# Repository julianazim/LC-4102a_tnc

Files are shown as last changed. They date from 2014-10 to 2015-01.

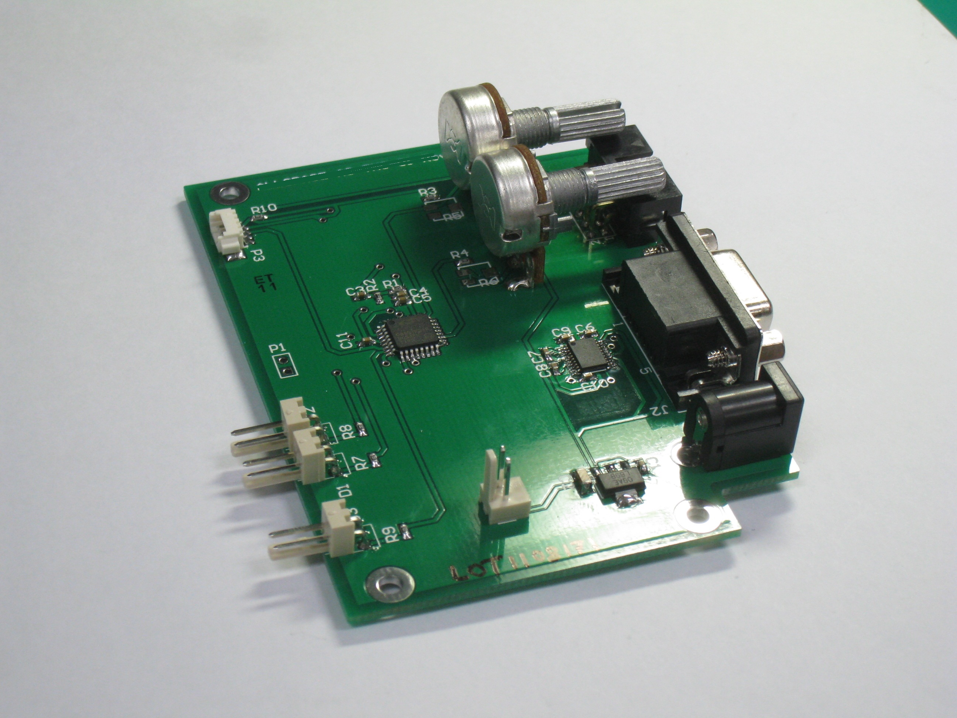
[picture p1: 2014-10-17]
documentation/pictures/IMG_1895.JPG

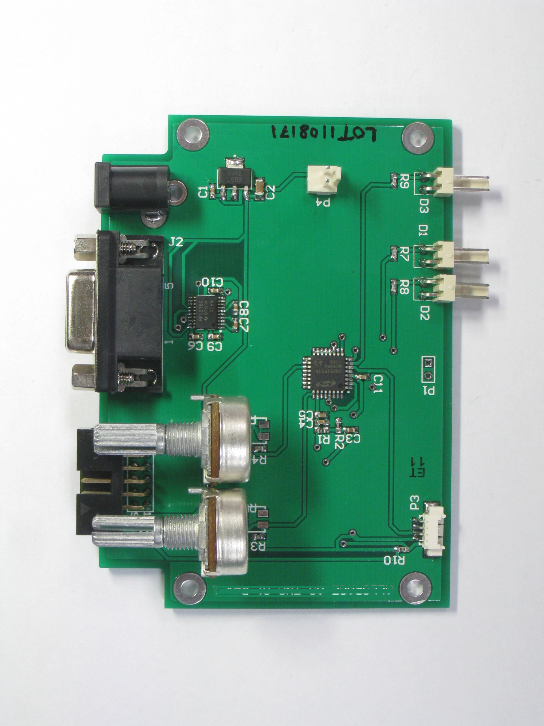
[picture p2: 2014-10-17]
documentation/pictures/IMG_1900.JPG

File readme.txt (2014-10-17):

--------------------------
LibreCube LC-4102a 1k2 TNC
--------------------------

OVERVIEW
--------
The LC-4102a 1k2 TNC Terminal Node Controller is used at the ground station
for interfacing between a computer system (running a mission control system)
and a radio system, for the  upload of telecommands and the reception of 
telemetry via the space link. The device is designed for the use of ECSS/CCSDS
conform telecommand and telemetry frames. It utilizes a simple protocol for
interfacing to a standard PC via serial port.

DISCLAIMER
----------
This product package is distributed in the hope that it will be useful, but 
WITHOUT ANY WARRANTY; without even the implied warranty of MERCHANTABILITY or 
FITNESS FOR A PARTICULAR PURPOSE. See the applicable licenses for more details.

AUTHORS
-------
Release a
* Artur Scholz <artur.scholz@cubesat.de>

ACKNOWLEDGEMENTS
----------------
The original work (Release a) was carried out at and with support from 
National Cheng Kung University (www.ncku.edu.tw) under supervision of 
Prof. Jiun-Jih Miau and Prof. Jyh-Ching Juang and with the help from students 
of PACELAB and MECLAB of National Cheng Kung University.

RELEASE HISTORY
---------------
Release a
* First release

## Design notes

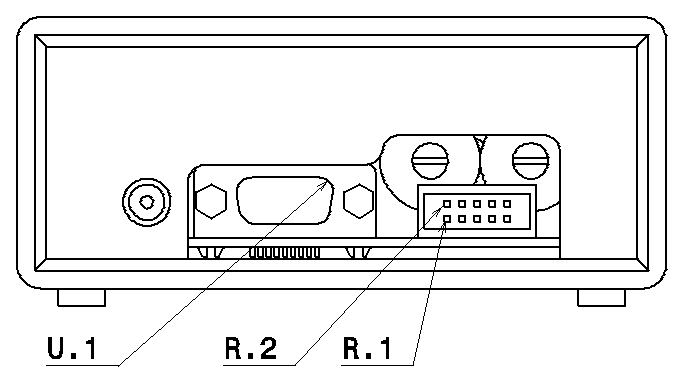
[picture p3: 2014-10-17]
documentation/figures/connector layout.tif

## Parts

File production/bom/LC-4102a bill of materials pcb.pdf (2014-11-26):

Sheet1

Page 1

LC-4102a Bill of Materials, PCB

Pos | Type | Description | Reference Designators | Qty | Vendor | Part Number | Unit Cost | Total Cost
1 | C | 0.1 uF | C1, C6, C7, C8, C9, C10, C11 | 7 | Digikey | 490-5241-1-ND | 0.10 € | 0.70 €
2 | C | 2.2 uF | C3 | 1 | Digikey | 587-1263-1-ND | 0.13 € | 0.13 €
3 | C | 10 uF | C2 | 1 | Digikey | 587-2562-1-ND | 0.56 € | 0.56 €
4 | C | 470 pF | C4, C5 | 2 | Digikey | 1276-2302-1-ND | 0.09 € | 0.18 €
5 | IC | C8051F310 | U3 | 1 | Digikey | 336-1252-ND | 3.86 € | 3.86 €
6 | IC | LM2937-3.3 | U1 | 1 | Digikey | LM2937IMP-3.3CT-ND | 1.93 € | 1.93 €
7 | IC | MAX3223 | U2 | 1 | Digikey | 296-13092-1-ND | 2.22 € | 2.22 €
8 | LED | LED1 | D1, D2, D3 | 3 | Digikey | 160-1447-1-ND | 0.26 € | 0.78 €
9 | P | DSUB9 | J2 | 1 | Digikey | 609-4009-ND | 0.83 € | 0.83 €
10 | P | Header 2 | P1, P4 | 2 | Digikey | 732-2699-ND | 0.51 € | 1.02 €
11 | P | Header 5X2-R | P2 | 1 | Digikey | 3M15452-ND | 0.65 € | 0.65 €
12 | P | MICRO-04-R-SMT | P3 | 1 | Digikey | WM7622CT-ND | 1.08 € | 1.08 €
13 | P | MINIJACK-1.3 | J1 | 1 | Digikey | CP-2519-ND | 0.76 € | 0.76 €
14 | R | 1 k | R3, R4, R7, R8, R9, R10 | 6 | Digikey | P1.0KGCT-ND | 0.09 € | 0.54 €
15 | R | 100 k | R2 | 1 | Digikey | P100KGCT-ND | 0.09 € | 0.09 €
16 | R | 120 k | R1 | 1 | Digikey | P120KGCT-ND | 0.09 € | 0.09 €
17 | R | 1 k | R5, R6 | 2 | Digikey | 987-1313-ND | 0.73 € | 1.46 €
Total: | 16.88 €

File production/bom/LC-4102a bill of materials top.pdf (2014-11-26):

Sheet1

LC-4102a Bill of Materials, Top Level

Item | Description | Reference Designators | Qty | Part Number (Digi-Key)
1 | PCB | | 1 | *produce
2 | Casing | | 1
3 | Power switch | | 1
4 | LED | | 3

Sheet1

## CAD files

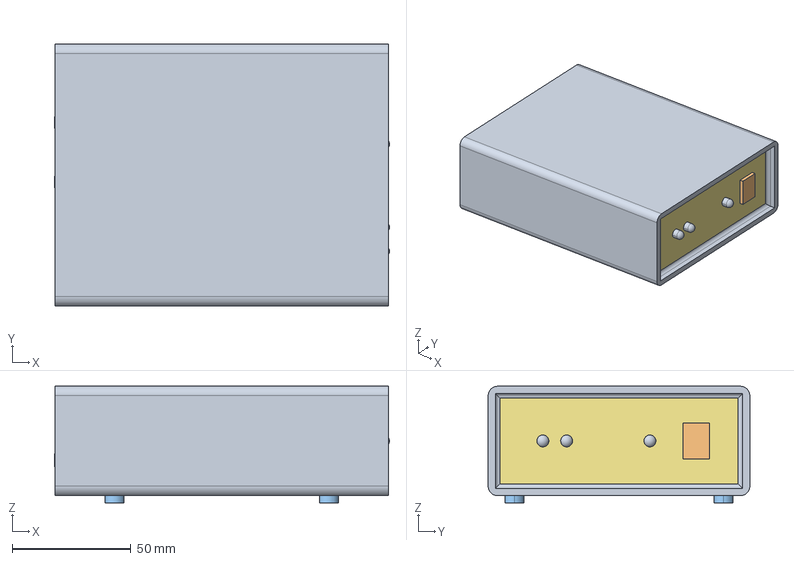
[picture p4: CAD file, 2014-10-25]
design/mechanical/assembly.stp
140.8 x 110.0 x 49.0 mm

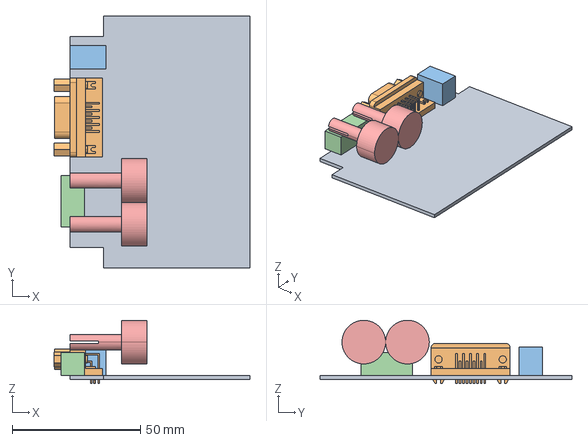
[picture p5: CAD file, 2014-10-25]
design/mechanical/board/pcb tnc assembly.stp
76.3 x 98.0 x 24.7 mm

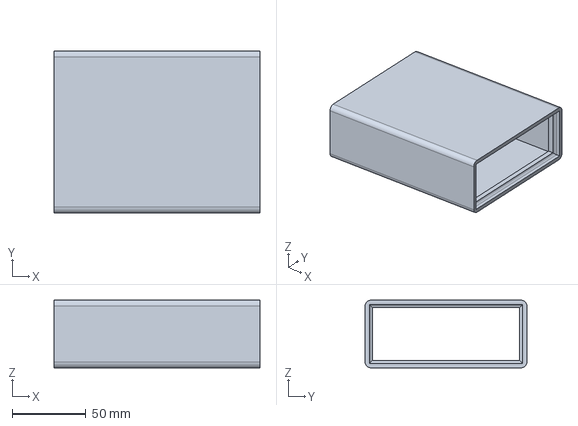
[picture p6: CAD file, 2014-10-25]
design/mechanical/parts/case.stp
140.0 x 110.0 x 46.0 mm

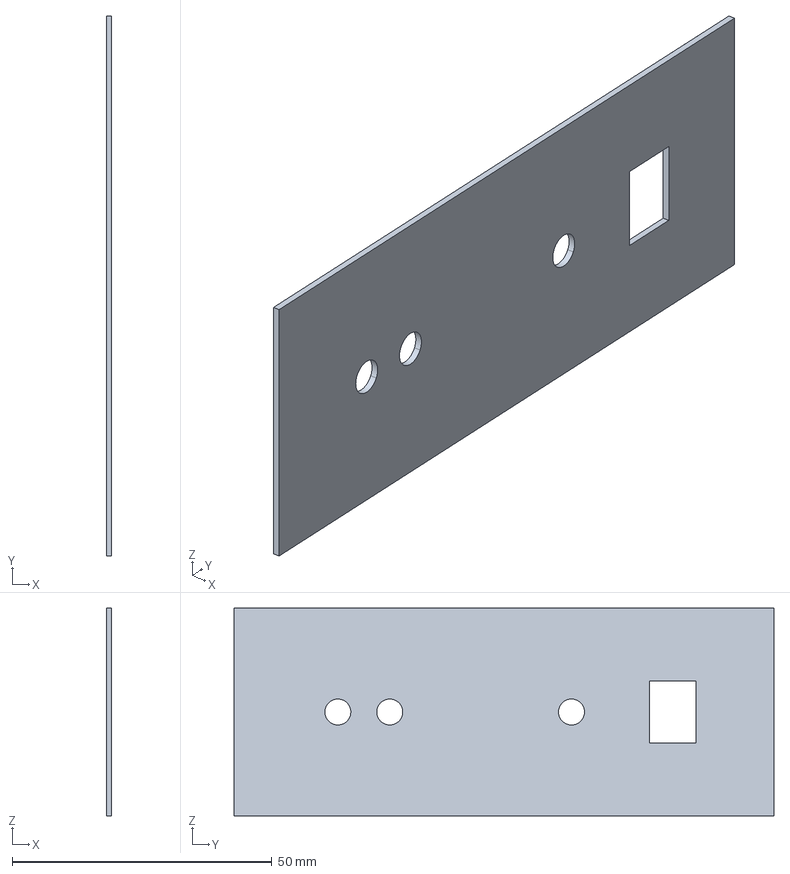
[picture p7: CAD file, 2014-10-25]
design/mechanical/parts/front panel.stp
1.00 x 104.0 x 40.0 mm

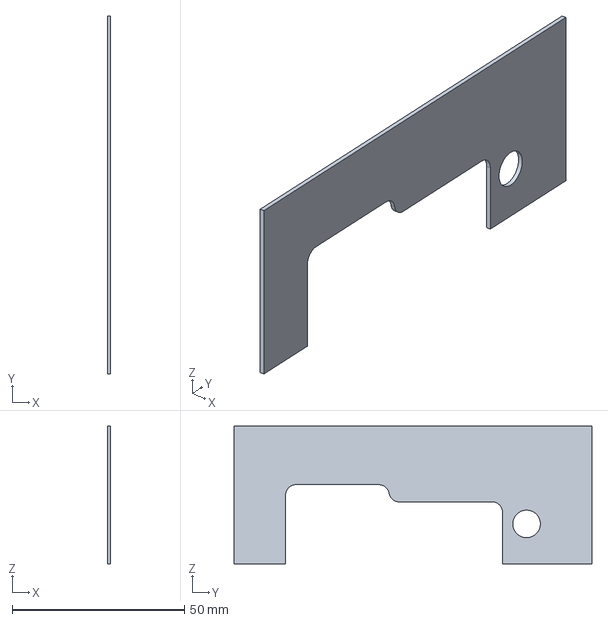
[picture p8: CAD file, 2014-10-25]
design/mechanical/parts/back panel.stp
1.00 x 104.0 x 40.0 mm

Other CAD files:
design/mechanical/assembly.CATProduct
design/mechanical/assembly.igs
design/mechanical/board/parts/connector.CATPart
design/mechanical/board/parts/dsub9.CATPart
design/mechanical/board/parts/pcb tnc.CATPart
design/mechanical/board/parts/plug.CATPart
design/mechanical/board/parts/poti.CATPart
design/mechanical/board/pcb tnc assembly.CATProduct
design/mechanical/board/pcb tnc assembly.igs
design/mechanical/parts/back panel.CATPart
design/mechanical/parts/back panel.igs
design/mechanical/parts/back panel.stl
design/mechanical/parts/case.CATPart
design/mechanical/parts/case.igs
design/mechanical/parts/case.stl
design/mechanical/parts/front panel.CATPart
design/mechanical/parts/front panel.igs
design/mechanical/parts/front panel.stl
design/mechanical/parts/led.CATPart
design/mechanical/parts/standoff.CATPart
design/mechanical/parts/switch.CATPart

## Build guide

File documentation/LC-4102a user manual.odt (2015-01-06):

LC-4102a

Terminal Node Controller

Document change log

Rev. | Date | Author | Pages | Description
0 | 2014-10-17 | Artur Scholz | All | Initial release

# Introduction

The LC-4102a Terminal Node Controller is used at the ground station for interfacing between a computer system (running a mission control system) and a radio system. The device is designed for the use of ECSS/CCSDS telecommand and telemetry frames. It utilizes a simple protocol for interfacing to a standard PC via serial port.

Features:

- ECSS/CCSDS frame protocol for telecommands
- Modified KISS protocol for TNC to PC communication
- Fixed FSK mode operation at 1200 bps

# Applicable and reference documents

Reference | Title | Issue
RD01 | KISS protocol, http://www.ax25.net/kiss.aspx | -
RD02 | ECSS-E-ST-50-01C, Space data links – Telemetry synchronization and channel coding | -
RD03 | ECSS-E-ST-50-04C, Space data links – Telecommand protocols synchronization and channel coding | -

# Definitions and abbreviations

Abbreviation | Definition
ASM | Attached sync marker
CADU | Channel Access Data Unit
CCSDS | Consultative Committee for Space Data Systems
CLTU | Communications Link Transmission Unit
ECSS | European Cooperation on Space Standardization
FEND | Frame end
FESC | Frame escape
KISS | Keep it simple, stupid
MSB | Most significant bit
PTT | Push to talk
RF | Radio frequency
RSSI | Received signal strength indication
TC | Telecommand
TFESC | Transposed frames escape
TM | Telemetry

# Specification

## Absolute maximum ratings

Parameter | Min | Max | Unit
Supply voltage | | 26 | V

## Physical characteristics

Parameter | Min | Nom | Max | Unit
Mass | | 225 | | g
Height | | 46 | | mm
Width | | 110 | | mm
Depth | | 140 | | mm

## Electrical characteristics

Parameter | Min | Nom | Max | Unit
Supply voltage | | 9 | | V
Power consumption | | | 4.5 | W
Microcontroller operating frequency | | 24.5 | | MHz
UART baud rate | | 115200 | | bps
DATAOUT output level | 0 | | 1.65 | V
DATAIN bias level | 0 | | 1.65 | V

## RF and protocol characteristics

Parameter | Min | Nom | Max | Unit
FSK baud rate | | 1200 | | bps
Size of CLTU | | | 140 | Byte
Fixed size of CADU | 16 | 64 | 2048 | Byte

# Interfaces

## Mechanical interfaces

The mechanical layout of the device and its dimensions are shown in Illustration 1. A short description of all items is provided in Table 1.

Illustration 1: Mechanical layout

Table 1: Description of front and back panel elements

Element | Function
RX LED | Indicates that frames are being received
TX LED | Indicates that transmission is active
POWER LED | Indicates that device is powered
POWER SWITCH | For switching the device on and off
POWER JACK | 9 Volt power supply input, ø2.1 mm, center positive
SERIALPORT CONNECTOR | Serial port for connection to PC
RADIO CONNECTOR | Connects to the radio
TX LEVEL ADJUSTMENT | Adjust output level for DATAOUT (TX)
RX BIAS ADJUSTMENT | Adjust bias level for DATAIN (RX)

## Electrical interfaces

The electrical interfaces to the device are shown in Illustration 2 and described in Table 2, Table 3, and Table 4.


Illustration 2: Connector layout

Table 2: Radio connector

Pin | Signal | Description
R.1 | - | Do not connect
R.2 | +3.3V | +3.3 Volt output
R.3 | ADJ0 | For adjustment
R.4 | DATAIN | Input for data (from external radio)
R.5 | ADJ1 | For adjustment
R.6 | -PTT | Push-to-talk input. Active low
R.7 | ADJ2 | For adjustment
R.8 | DATAOUT | Output of data (to external radio)
R.9 | GND | Ground
R.10 | GND | Ground

* Only the bold printed connections need to be wired to the radio

Table 3: Serial port connector

Pin | Signal | Description
U.2 | RXD_TTL | RXD (TTL level)
U.3 | TXD_TTL | TXD (TTL level)
U.5 | GND | Ground

Table 4: Programming interface connector

Pin | Signal | Description
PI.1 | +3.3V | +3.3V power supply
PI.2 | C2D | C2 programming interface data
PI.3 | C2CK | C2 programming interface clock
PI.4 | GND | Ground.

* This connector is located on the PCB.

| The programming interface is used for updating the firmware.

## Software interfaces

Interfacing between the TNC and a computer for transfer of beacon/telemetry and telecommand data is accomplished via the UART bus.

The protocol is kept very simple, in close analogy to the KISS protocol (RD01). Data is transferred in frames between master and slave, one frame after the other. Frames are delimited by a special FEND (Frame End) character at the start and end. The first byte of a frame following the delimiter indicates the type of data in the frame.

FEND | CMD | Data | Data | Data | Data | ... | Data | FEND

The values of the special characters are:

FEND Frame End 0xC0

FESC Frame Escape 0xDB

TFEND Transposed Frame End 0xDC

TFESC Transposed Frame Escape 0xDD

In case that a FEND character appears in the data, it is translated into the two byte sequence FESC TFEND (Frame Escape, Transposed Frame End). Likewise, if the FESC character ever appears in the user data, it is replaced with the two character sequence FESC TFESC (Frame Escape, Transposed Frame Escape).

As characters arrive at the receiver side, they are appended to a buffer containing the current frame. Receiving a FEND marks the end of the current frame. Receipt of a FESC puts the receiver into "escaped mode", causing the receiver to translate a following TFESC or TFEND back to FESC or FEND, respectively, before adding it to the receive buffer and leaving escaped mode. Receipt of any character other than TFESC or TFEND while in escaped mode is an error; no action is taken and frame assembly continues. A TFEND or TESC received while not in escaped mode is treated as an ordinary data character.

The CMD byte can have take following values:

UPLINK_CLTU 0x01 CLTU to be sent from computer to TNC

DOWNLINK_CADU 0x02 CADU received from TNC to computer

HANDSHAKE 0x0A Handshake (answer)

TEST_CONNECTION 0x0B Test port connection

TX_STATE 0x0C Transmitter state (on/off)

IDLE_SEQUENCE 0x0D Send idle pattern (on/off)

CADU_LENGTH 0x0E Set the fixed CADU length

See Section Operations on how to use those commands.

# Design description

## Hardware description

The TNC consists of a power conditioner, a UART interface module, and microcontroller. The microcontroller handles the interfacer to the computer via the UART interface module. It further provides the interface to an external radio, and conditions its input and output.

For the output of data to the external radio (i.e. DATAOUT line), it provides the capability to adjust the signal level for a binary '1' from 0V to 1.65V (binary '0' is always at ground).

For the input of data from the external radio (i.e. DATAIN line) it first removes the DC offset from the signal through a high pass filter. It then compares the incoming signal level with an adjustable reference signal level, to discriminate between binary '1'and '0'.

## Software description

The TNC provides is the node between computer and radio system for sending telecommand frames (CLTUs) and receiving telemetry frames (CADUs).

When not sending, the TNC continuously reads from the radio output, shifts these bits into a small buffer, and checks if the synch pattern (ASM) has been detected. It then receives the CADU (i.e. telemetry) frame bit for bit, shifts it into an octet buffer (i.e. byte buffer) and sends appends each completed octet to the frame being send to the computer via the KISS protocol. Since CADU frames have fixed length, the TNC knows when a full CADU has been received and then terminates the transfer to the computer.

For sending of CLTUs (i.e. telecommands) the computer first switches on the transmitter, then activates the sending of acquisition sequence (which is composed of idle pattern) and then transfers the CLTU via the KISS protocol to the TNC. Once the whole CLTU has been transferred, the TNC starts to transmit the CLTU bit stream to the radio, provided that the transmitter is left enabled. The computer finishes the transmit session by switching of the transmitter.

# Installation

## Making the connections

Plug a serial cable to the device and connect it with a PC (for example by using a serial to USB cable). Make sure that the device power switch is off and then plug a 9V power supply to the device. Finally, connect the bold written pins in Table 2 from the device’s radio connector to the radio’s data connector. For proper operation, the device must be adjusted to the radio’s signal levels. This is described in the next sections.

## Transmit adjustments

Refer to your radio for the specification on the recommended and allowable input levels on its DATA IN pin. Commonly this is about 0.4 Vpeak-peak.

To adjust the output level of the DATAOUT signal, temporarily disconnect the DATAOUT signal line from the device’s radio connector and measure its voltage level. Rotate the TX LEVEL ADJUSTMENT potentiometer clockwise to increase and counter-clockwise to decrease the output level to the desired value.

| Note: Same commercial radios output an inverted bit stream. In such case, one needs to set the bit invert flag in the TNC.

## Receive adjustments

The device requires that the radio recovers the FSK modulated baseband signal from the RF signal fairly accurately. Internally, the device decouples and filters the signal provided by the radio and makes this signal available at the ADJ1 pin. An example of this signal when the radio receives only noise is shown in Illustration 3. Make sure that your radio is tuned properly to produce similar results. Determine the mean value of this signal, as shown as the red line.

Illustration 3: Raw signal from radio (top) and filtered signal at ADJ1 (bottom)

Next, adjust the signal at the ADJ2 pin to this previously determined mean value, by using the RX BIAS ADJUSTMENT potentiometer clockwise for decrease or counter-clockwise for increase. The meaning of this bias voltage is that every signal level of the filtered signal in Illustration 4 that is above this threshold will be converted to 3.3 V whereas all signals below this threshold will be converted to 0V (CMOS level) for use by the TNC. As a last step, measure the signal at ADJ0 to see the recovered binary sequence in CMOS level.

Illustration 4: The filtered radio signal (top) correctly converted into CMOS level (bottom).

# Operations

## Testing the connection

To ensure that the device is connected correctly to the computer and the KISS frames exchange works properly, the TEST_CONNECTION command can be used.

The computer sends an TEST_CONNECTION frame via the serial port, with following structure:

FEND | CMD | FEND

Where CMD = TEST_CONNECTION. The TNC then responds with an acknowledge frame:

FEND | CMD | FEND

Where CMD = HANDSHAKE.

## Adjusting TNC settings

So far, the only setting that can be adjusted via software is the length of the CADU frame. CADU frames have (mission) fixed length. This is so because they only have markers for the start of a frame (i.e. the attached synch marker) and not for the frame end. Therefore they must be fixed length, to let the TNC know when the frame is complete.

## Receiving

When not transmitting, the TNC is constantly in receive mode. It searches the incoming bit stream from the radio for the synch pattern (ASM), which marks the begin of a CADU, which is used to transport telemetry from the spacecraft. The structure of a CADU is as follows:

CADU – Channel Access Data Unit
Attached Synch Marker 0x1ACFFC1D | Data
4 byte | Fixed, max. 2048 byte

When the TNC has detected an ASM, it will start a KISS frame transfer (sending a FEND) and then transfer the received CADU while it is being received, as follows:

FEND | CMD | CADU | FEND

Where CMD = DOWNLINK_CADU. Note again that the CADU frame is transferred at the same time while it is being received, meaning that there is no buffering of the whole CADU at the TNC. This is possible because the UART connection always to introduce delays in the transfer.

## Transmitting

For transmitting CLTUs (i.e. telecommands), the computer shall operate the TNC in the following manner.

First, the transmitter must be turned on. This is accomplished via the following KISS frame:

FEND | CMD | PAR | FEND

Where CMD = TX_STATE, and PAR = ON. This mode is equivalent to CMM-1 “Unmodulated carrier only”, as defined in RD03.

Then the sending of the acquisition sequence shall be activated, which is an idle pattern, i.e. a sequence of alternating “ones” and “zeros” starting with either a “one” or a “zero”. This is a preamble that provides for initial symbol synchronization for the received on board the satellite. It should be sending at least 128 bits before switching to CMM-3. The command is as follows:

FEND | CMD | PAR | FEND

Where CMD = IDLE_SEQUENCE, and PAR = ON. This mode is equivalent to CMM-2 “Carrier modulated with acquisition sequence”, as defined in RD03.

Then the sending of a CLTU can be initiated as follows:

FEND | CMD | CLTU | FEND

Where CMD = UPLINK_CLTU and the CLTU is structured as follows:

CLTU – Command Link Transmission Unit
Start Sequence 0xEB90 | 1st Codeblock | 2nd Codeblock | ... | n-th Codeblock | Tail sequence
2 byte | 8 byte | 8 byte | | 8 byte | 8 byte

A CLTU is of variable length and terminated by a tail sequence, which can be either:

“0xC5 0xC5 0xC5 0xC5 0xC5 0xC5 0xC5 0x79” or “0x55 0x55 0x55 0x55 0x55 0x55 0x55 0x55”

The sending of a CLTU is described as mode CMM-3 “Carrier modulated with telecommand data”, as defined in RD03. Several CLTUs can be send during one transmit session (i.e. while the transmitter is on), provided that there is a small amount of idle bits being sent in between (which is then defined as mode CMM-4 “Carrier modulated with idle sequence”). The length of the idle sequence shall be at least 8 bits. This is achieved easily by waiting for short delay between the sending of CLTUs, while sending of acquisition sequence is left enabled. The transmit session is ended by stopping the transmission of the acquisition sequence and switching of the transmitter (see IDLE_SEQUENCE and TX_STATE commands above, both with parameter OFF).

Terminal Node Controller Ref : LC-4102a-MAN-001 Issue : 1 Rev. : 0 Date : 2014-10-17 Page : 14

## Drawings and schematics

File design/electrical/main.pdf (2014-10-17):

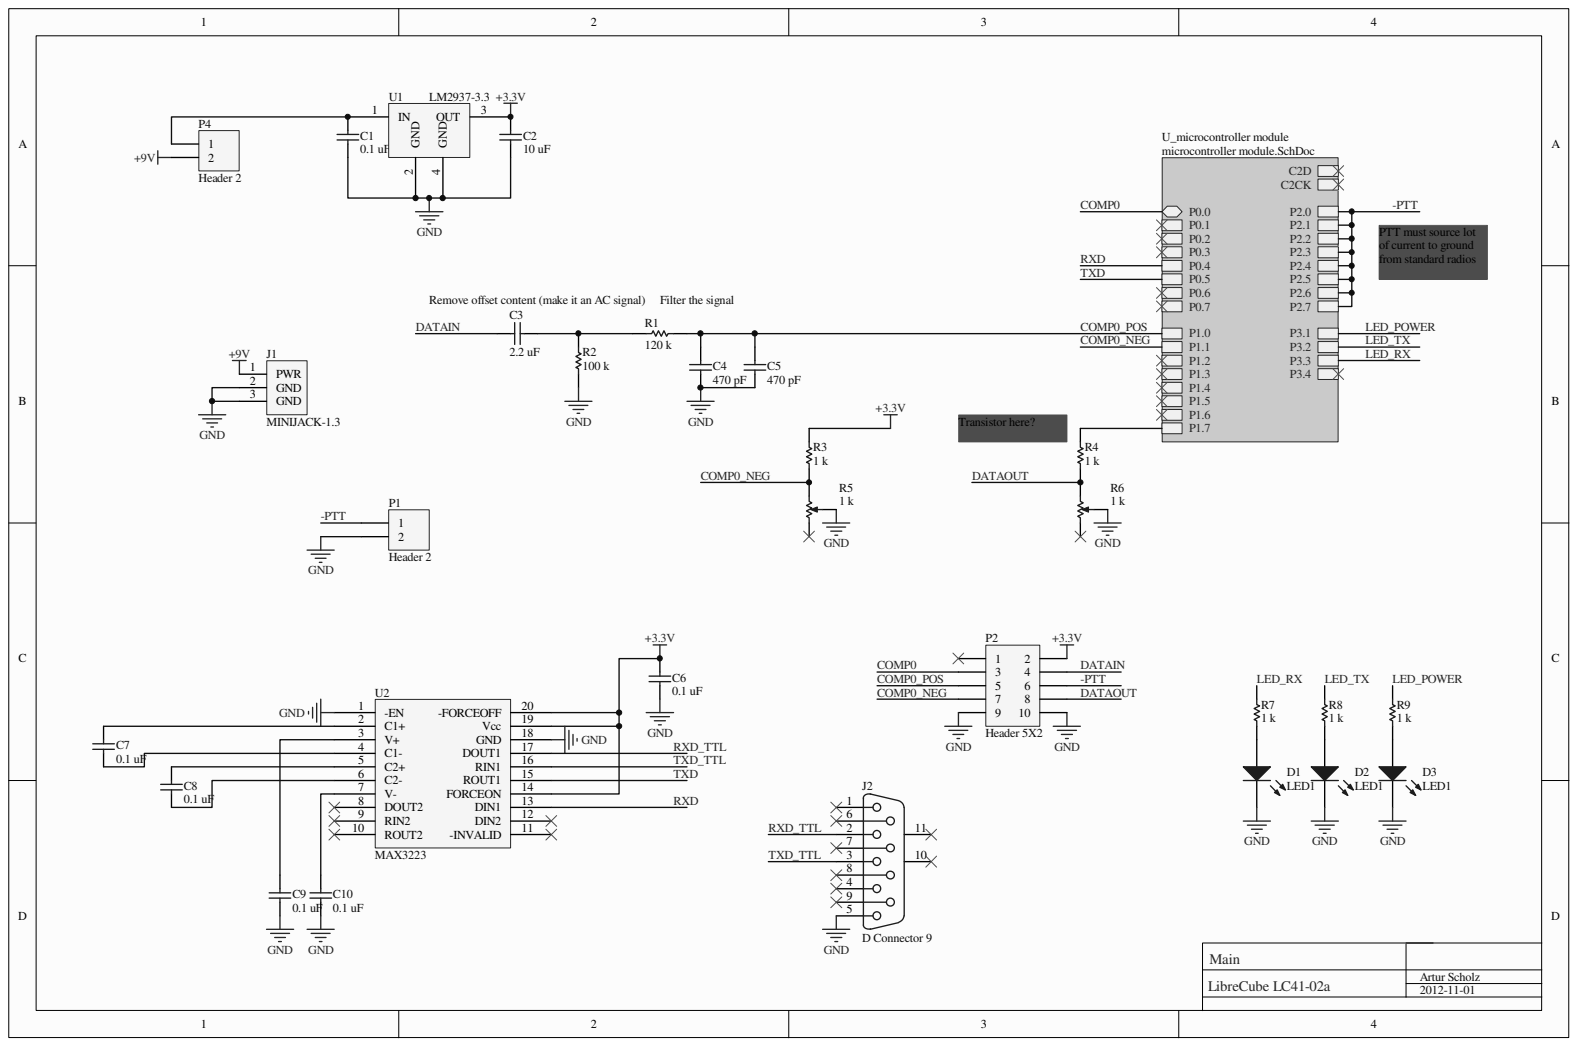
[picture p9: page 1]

PTT must source lot
of current to ground
from standard radios

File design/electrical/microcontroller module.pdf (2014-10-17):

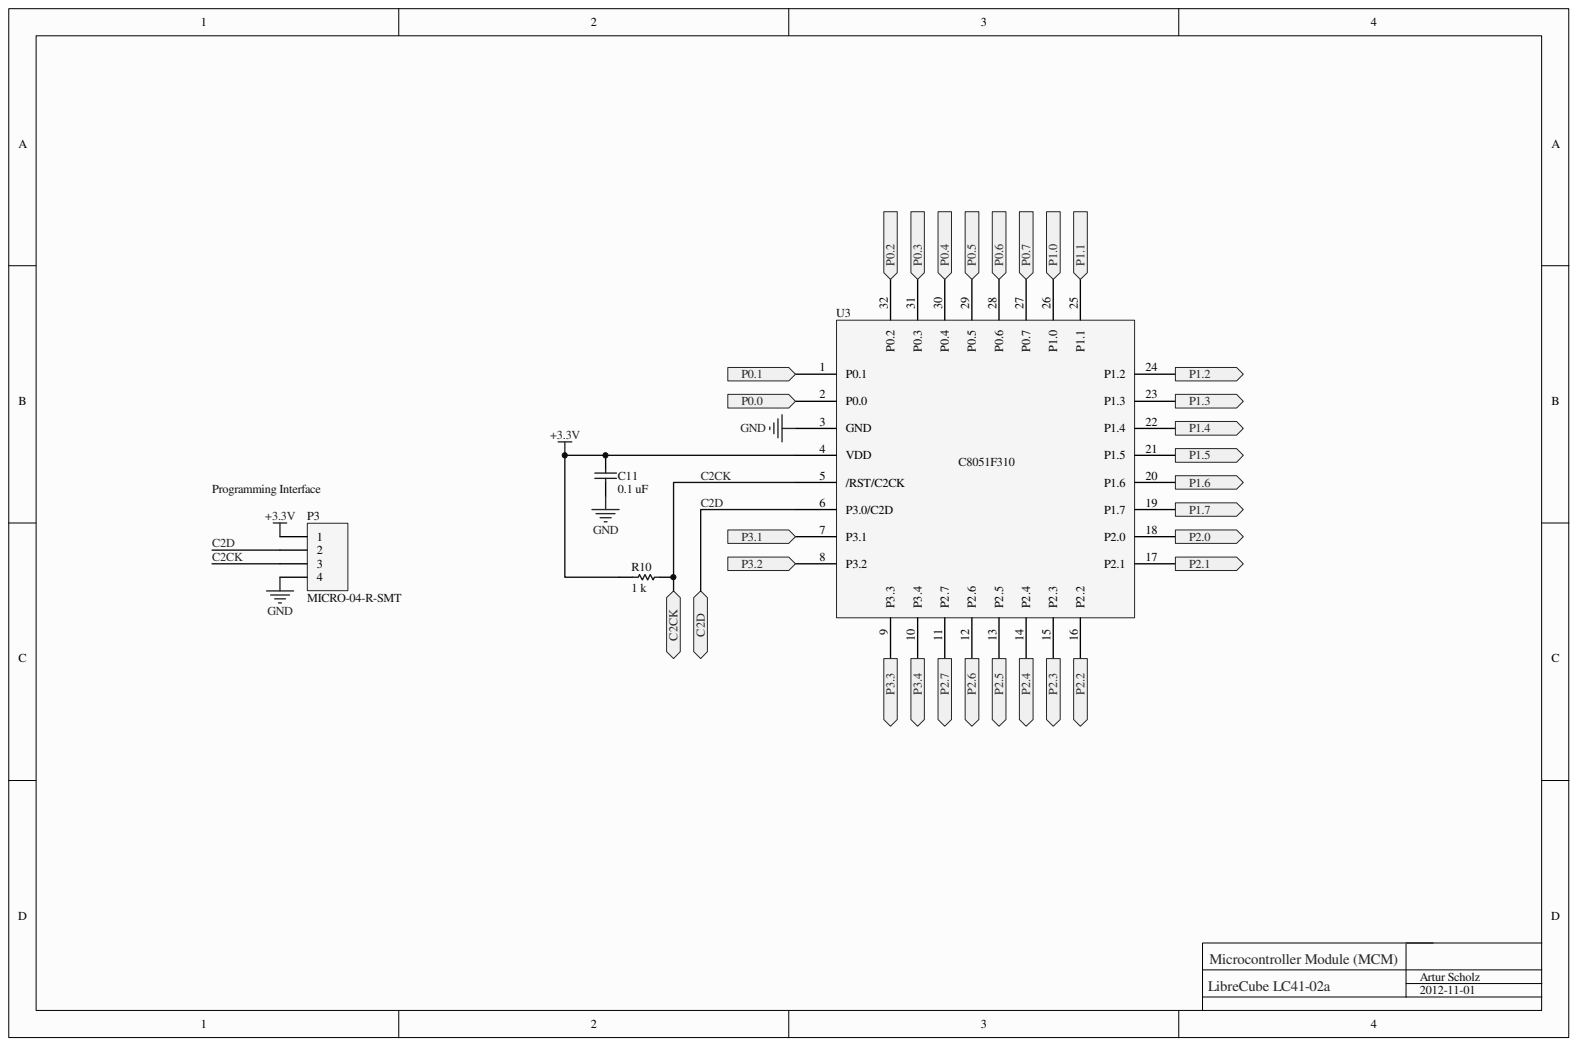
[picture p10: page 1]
Artur Scholz; LibreCube LC41-02a; MICRO-04-R-SMT; GND; Programming Interface; GND 3; VDD 4; /RST/C2CK 5

Microcontroller Module (MCM)

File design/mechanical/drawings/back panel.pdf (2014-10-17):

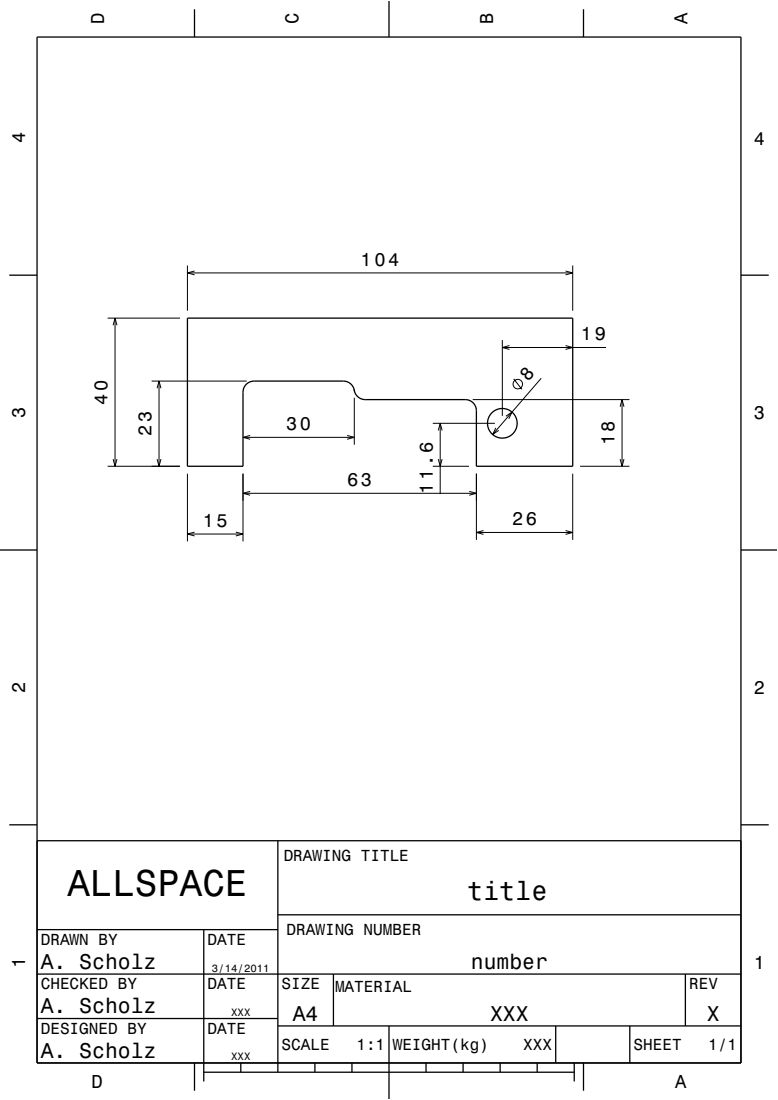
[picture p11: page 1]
DRAWING NUMBER; DRAWING TITLE

DRAWN BY A. Scholz | DATE 3/14/2011

CHECKED BY A. Scholz | DATE XXX | SIZE A4 | MATERIAL XXX | REV X

DESIGNED BY A. Scholz | DATE XXX

SCALE 1:1 | WEIGHT(kg) XXX | SHEET 1/1

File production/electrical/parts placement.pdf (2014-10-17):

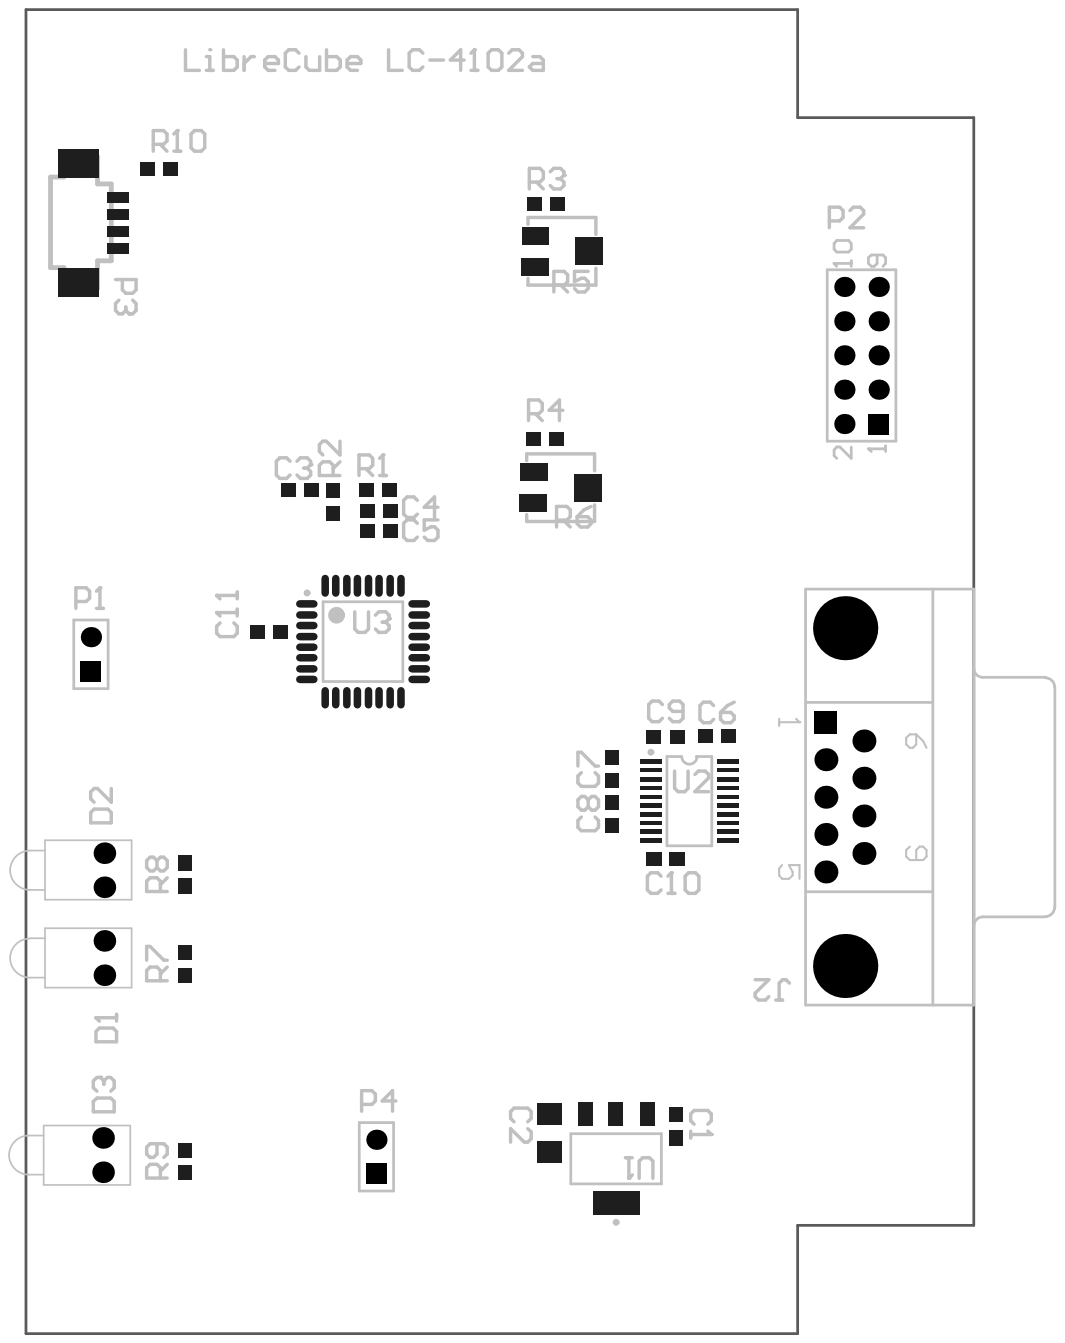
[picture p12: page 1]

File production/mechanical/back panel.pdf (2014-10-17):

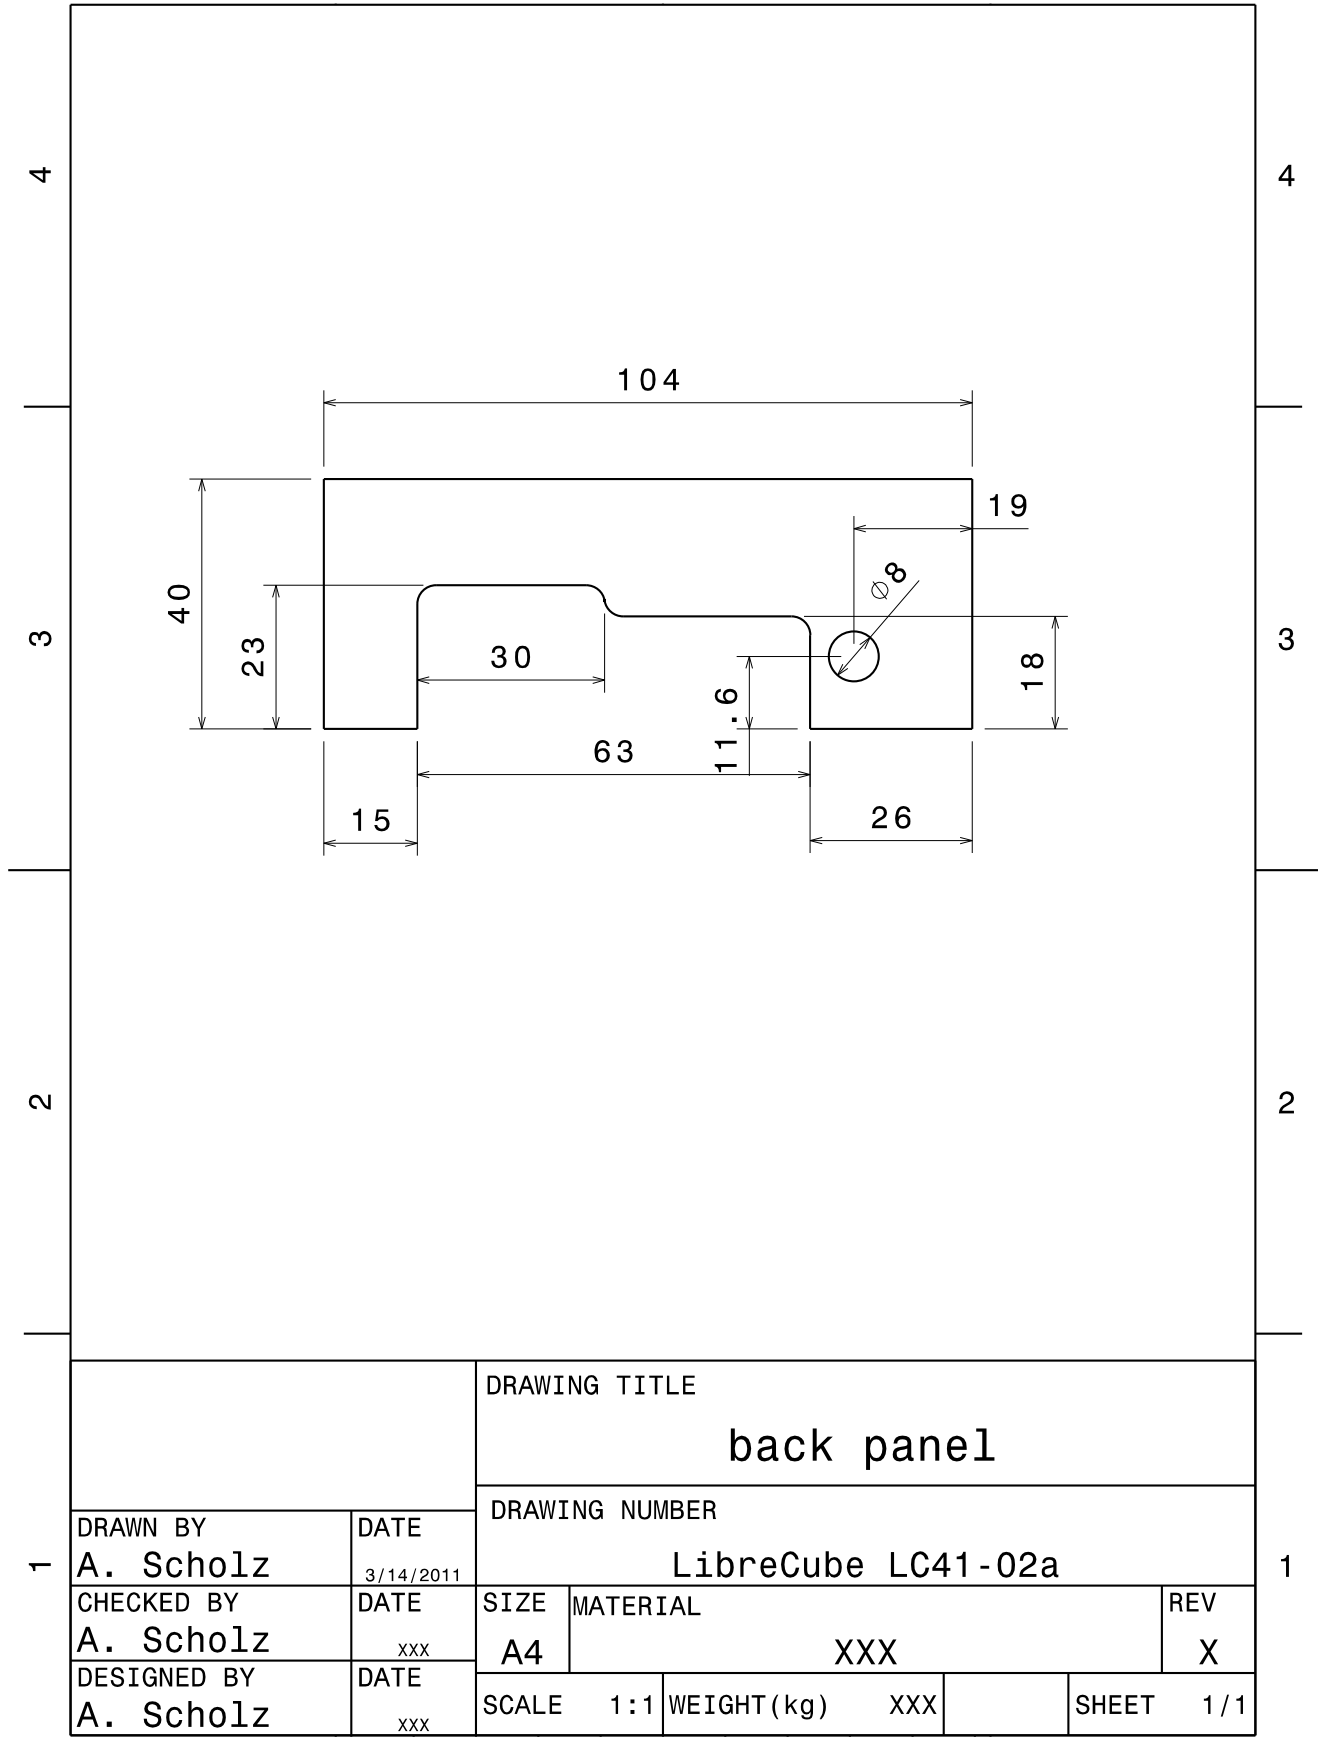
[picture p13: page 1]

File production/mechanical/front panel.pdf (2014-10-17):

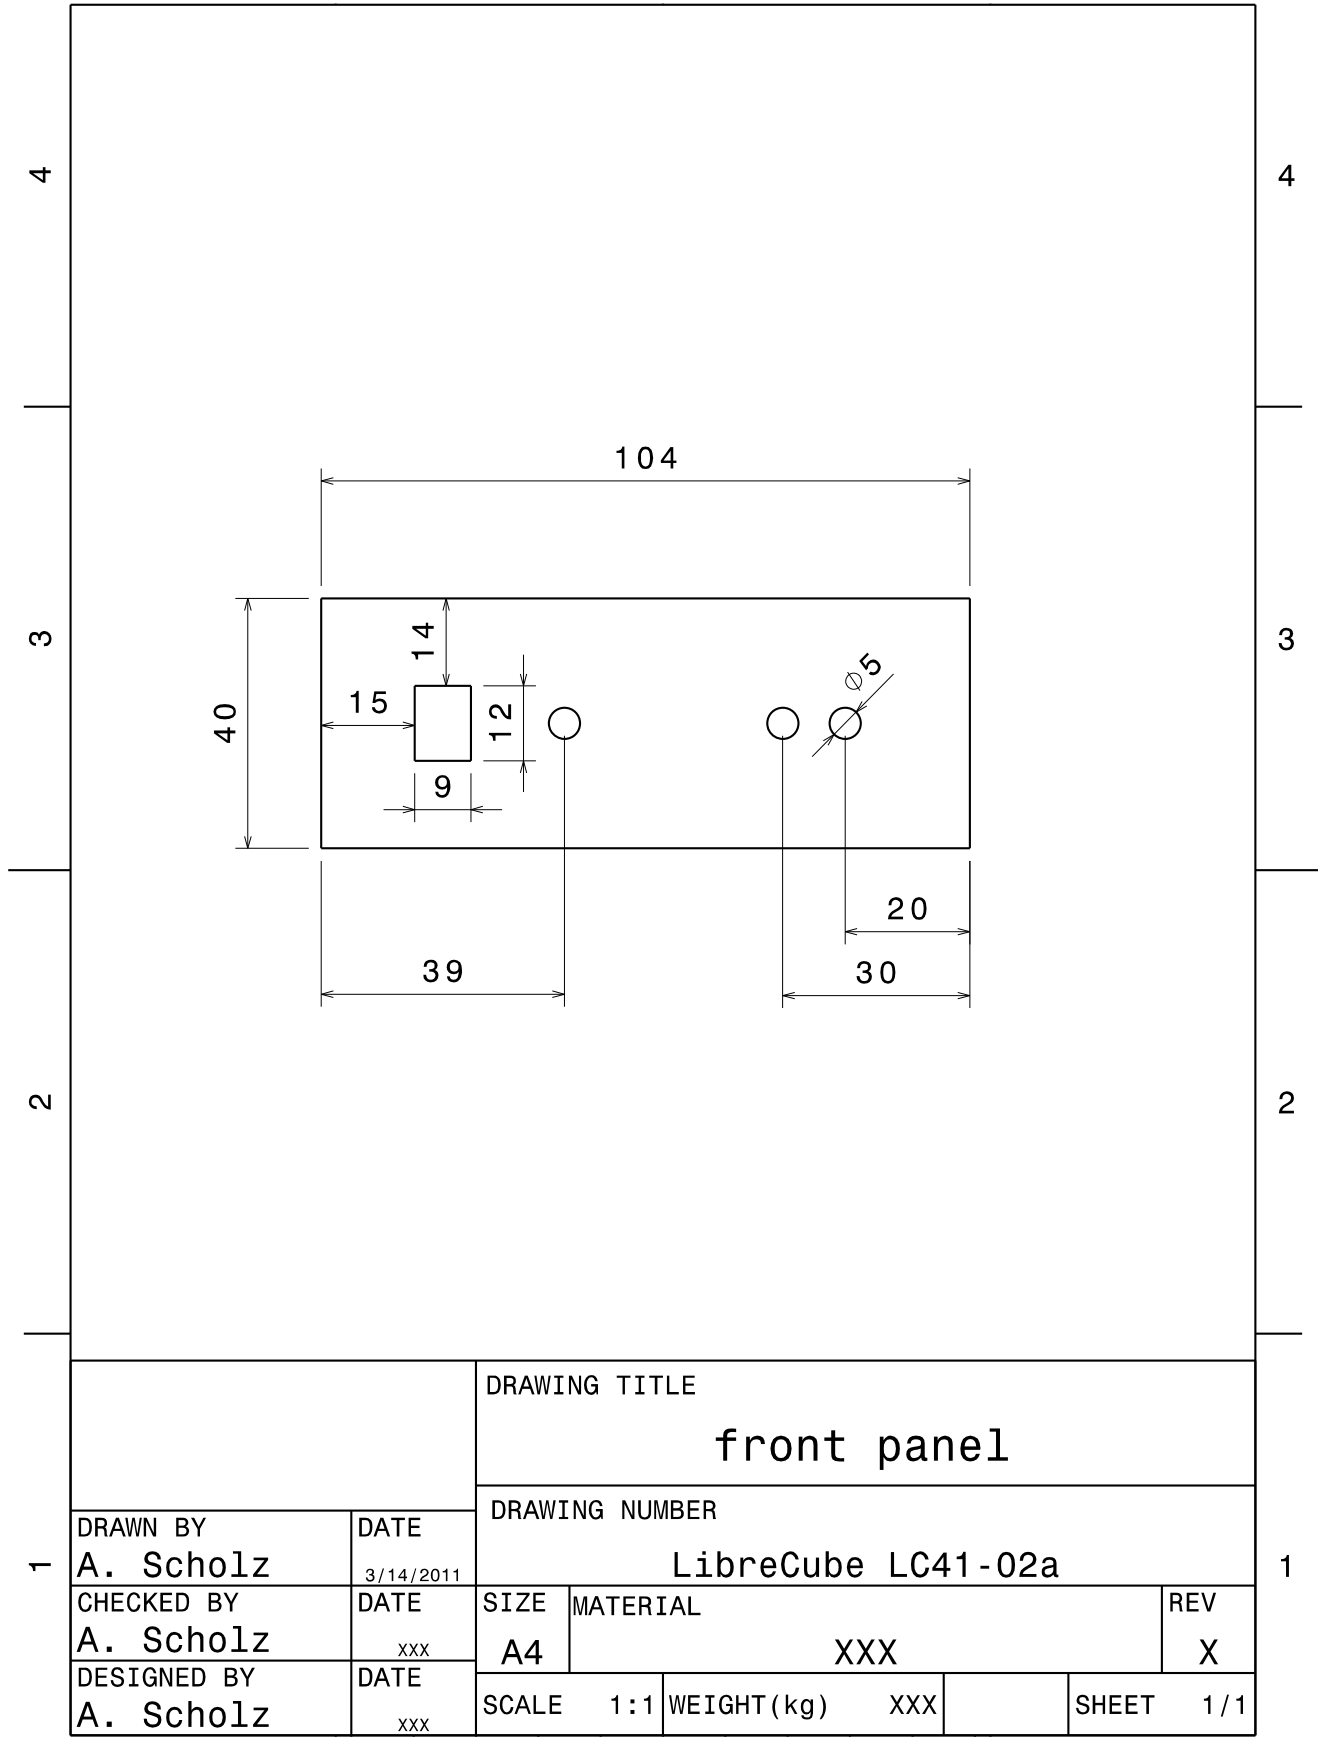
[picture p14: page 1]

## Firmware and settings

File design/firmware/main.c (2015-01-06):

/* --------------------------
 * LibreCube LC-4102a 1k2 TNC
 * --------------------------
 * Last update: 2014-10-17 
 */

/* 	Summary:
 *		The TNC provides is the node between computer and radio system for sending 
 *		telecommand frames (CLTUs) and receiving telemetry frames (CADUs).
 *		
 *      When not sending, the TNC continuously reads from the radio output, 
 *      shifts these bits into a small buffer, and checks if the synch pattern
 *      (ASM) has been detected. It then receives the CADU (i.e. telemetry) frame
 *      bit for bit, shifts it into an octet buffer (i.e. byte buffer) and sends
 *      appends each completed octet to the frame being send to the computer
 *      via the KISS protocol. Since CADU frames have fixed length, the TNC 
 *      knows when a full CADU has been received and then terminates the 
 *      transfer to the computer.
 *      
 *		For sending of CLTUs (i.e. telecommands) the computer first switches on 
 *		the transmitter, then activates the sending of acquisition sequence 
 *		(which is composed of idle pattern) and then transfers the CLTU via
 *		the KISS protocol to the TNC. Once the whole CLTU has been transferred,
 *		the TNC starts to transmit the CLTU bit stream to the radio, provided
 *		that the transmitter is left enabled. The computer finishes the transmit
 *		session by switching of the transmitter.
 *
 *	Configuration:
 *		- uart baudrate (115200)
 *		- modem baudrate (1k2)
 *		- maximum cltu buffer size (210 octets)
 *		- default cadu length (64 octets)
 *
 *	To do:
 *		- allow option of inverted uplink bit stream?
 */

/* Includes */
#include "definitions.h"
#include "functions/downlink.h"
#include "functions/uplink.h"

/* Globals */
__xdata uint8_t cltuBuffer[CLTU_BUFFER_SIZE]; /* buffers a CLTU from the PC for sending */
uint8_t cltuReceived = CLEAR; /* flags if CLTU was received form computer */
uint8_t idleSequence = CLEAR; /* flags if idle sequence shall be transmitted */
uint8_t transmitterMode = OFF; /* flags if transmitter shall be on */
uint16_t octetCount = 0; /* counts the length of the buffered CLTU */
uint16_t caduLength = DEFAULT_CADU_LENGTH; /* defines the fixed length of CADU telemetry frames */

void main(void)
{
    uint32_t i;
    
    MicrocontrollerInit();
    LED_POWER = ON; /* Power LED on */
    _PTT = PTT_OFF; /* Transmitter (via Push-to-talk) off */
    
	/* Show all LEDs at power-up */
    LED_TX = ON;
    LED_RX = ON;
    for (i = 0; i < 1000000UL; i++); 
    LED_TX = OFF;
    LED_RX = OFF;   
    
    for (;;)
    {       
        if (transmitterMode == ON)
        {
            if (cltuReceived) /* send CLTU if available */
            {
                cltuReceived = CLEAR;
                SendCltu(cltuBuffer, octetCount);
            }
            else if (idleSequence) /* otherwise send idle pattern if enabled */
            {
                SendIdle();
            }         
        }
        else /* TNC is in receiving mode */
        {
            if (DetectCaduAsm() == PASS) /* if the synch marker is detected from radio */
            {
                LED_RX = ON;
                ReceiveCadu(caduLength); /* receive and forward the telemetry */
                LED_RX = OFF;
            }
        }
    }
}

void UartIsr(void) __interrupt 4
{
    static uint8_t uartBuffer = 0;
    
    if (RI0) /* byte received */
    {
        uartBuffer = SBUF0;
        if (uartBuffer == FEND) /* FENDs mark the begin and end of a frame */
        {
            cltuReceived = CLEAR; /* reset all counters */
            octetCount = 0;
            RI0 = 0;
        }
        else /* this byte contains the CMD */
        {
            switch (uartBuffer)
            {
                case TEST_CONNECTION: /* test UART connection */
                    for (;;) /* read remaining bytes of KISS frame */
                    {
                        RI0 = 0;
                        while (!RI0)
                            ;
                        uartBuffer = SBUF0;
                        if (uartBuffer == FEND)
                            break;
                    }
                    
                    TI0 = 0;
                    SBUF0 = FEND; /* send KISS frame start */
                    while (!TI0)
                        ;
                    TI0 = 0;
                    SBUF0 = HANDSHAKE; /* send HANDSHAKE */
                    while (!TI0)
                        ;
                    TI0 = 0;
                    SBUF0 = FEND;
                    while (!TI0)
                        ;
                    break;
                    
                case CADU_LENGTH: /* program fixed CADU length */
                    RI0 = 0;
                    while (!RI0)
                        ;
                    uartBuffer = SBUF0;
                    RI0 = 0;
                    while (!RI0)
                        ;
                    caduLength = uartBuffer + ((uint16_t) SBUF0 << 8);
                    break;
                    
                case TX_STATE: /* set transmitter state */
                    
                    RI0 = 0;
                    while (!RI0)
                        ;
                    uartBuffer = SBUF0;
                    
                    if (uartBuffer == ON) /* set transmitter on */
                    {
                        transmitterMode = ON;
                        _PTT = PTT_ON;
                        LED_TX = ON;
                    }
                    else /* set transmitter off */
                    {
                        transmitterMode = OFF;
                        _PTT = PTT_OFF;
                        LED_TX = OFF;
                    }
                    break;
                    
                case IDLE_SEQUENCE: /* enable or disable sending of idle sequence */
                    
                    RI0 = 0;
                    while (!RI0)
                        ;
                    uartBuffer = SBUF0;
                    
                    if (uartBuffer == ON)
                    {
                        idleSequence = ON;
                    }
                    else if (uartBuffer == OFF)
                    {
                        idleSequence = OFF;
                    }
                    
                    break;
                    
                case UPLINK_CLTU: /* buffer data (CLTU) from computer (to be uplinked) */
                    for (;;)
                    {
                        RI0 = 0;
                        while (!RI0)
                            ;
                        uartBuffer = SBUF0;
                        
                        if (uartBuffer == FEND)
                            break;
                        
                        if (uartBuffer == FESC)
                        {
                            RI0 = 0;
                            while (!RI0)
                                ;
                            uartBuffer = SBUF0;
                            
                            if (uartBuffer == TFESC)
                                uartBuffer = FESC;
                            else if (uartBuffer == TFEND)
                                uartBuffer = FEND;
                        }
                        
                        cltuBuffer[octetCount] = uartBuffer;
                        if (octetCount < (CLTU_BUFFER_SIZE - 1))
                            octetCount++;
                    }
                    cltuReceived = SET; /* frame with data received */
                    break;
            }
            
            RI0 = 0;
        }
    }
    
    if (TI0)    // byte sent
    {
        TI0 = 0;
    }
}

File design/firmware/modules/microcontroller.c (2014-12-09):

/* --------------------------------
 * LibreCube LC41-01a UHF FSK Radio
 * --------------------------------
 */

#include "microcontroller.h"

void Reset_Sources_Init()
{
    uint16_t i = 0;
    VDM0CN = 0x80;
    for (i = 0; i < 350; i++)
        ;    // Wait 100us for initialization
}

void PCA_Init() /* disable watch dog */
{
    PCA0MD &= ~0x40;
    PCA0MD = 0x00;
}

void Timer_Init()
{
    TCON = 0x50;
    TMOD = 0x21;
    CKCON = 0x09;
    TH1 = 0x96;
}

void UART_Init()
{
    SCON0 = 0x10;
}

void Comparator_Init()
{
    uint16_t i = 0;
    CPT0CN = 0x8F;
    for (i = 0; i < 35; i++)
        ;    // Wait 10us for initialization
    CPT0CN &= ~0x30;
    CPT0MD = 0x03;
}

void Voltage_Reference_Init()
{
    REF0CN = 0x0E;
}

void Port_IO_Init()
{
    // P0.0  -  CP0 (Cmp0),  Push-Pull,  Digital
    // P0.1  -  Unassigned,  Open-Drain, Digital
    // P0.2  -  Unassigned,  Open-Drain, Digital
    // P0.3  -  Unassigned,  Open-Drain, Digital
    // P0.4  -  TX0 (UART0), Push-Pull,  Digital
    // P0.5  -  RX0 (UART0), Open-Drain, Digital
    // P0.6  -  Unassigned,  Open-Drain, Digital
    // P0.7  -  Unassigned,  Open-Drain, Digital
    
    // P1.0  -  Skipped,     Open-Drain, Analog
    // P1.1  -  Skipped,     Open-Drain, Analog
    // P1.2  -  Unassigned,  Open-Drain, Digital
    // P1.3  -  Unassigned,  Open-Drain, Digital
    // P1.4  -  Unassigned,  Open-Drain, Digital
    // P1.5  -  Unassigned,  Open-Drain, Digital
    // P1.6  -  Unassigned,  Open-Drain, Digital
    // P1.7  -  Unassigned,  Push-Pull,  Digital
    // P2.0  -  Unassigned,  Push-Pull,  Digital
    // P2.1  -  Unassigned,  Push-Pull,  Digital
    // P2.2  -  Unassigned,  Push-Pull,  Digital
    // P2.3  -  Unassigned,  Push-Pull,  Digital
    
    P1MDIN = 0xFC;
    P0MDOUT = 0x11;
    P1MDOUT = 0x80;
    P2MDOUT = 0xFF;
    P3MDOUT = 0x1F;
    P1SKIP = 0x03;
    XBR0 = 0x11;
    XBR1 = 0x40;
}

void Oscillator_Init()
{
    OSCICN = 0x83;
}

void Interrupts_Init()
{
    IE = 0x90;
}

void MicrocontrollerInit(void)
{
    PCA_Init();
    Reset_Sources_Init();
    Timer_Init();
    UART_Init();					// 115200 bps
    Comparator_Init();
    Voltage_Reference_Init();
    Port_IO_Init();
    Oscillator_Init();
    Interrupts_Init();
}

void TimerWait(const uint16_t duration)
{
    uint16_t i;
    
    TL0 = 0;
    TH0 = 0;
    do
    {
        i = (uint16_t) (TH0 << 8) + TL0;
    }
    while (i < duration);
}

void TimerReset(void)
{
    TH0 = 0;
    TL0 = 0;
}

uint8_t TimerElapsed(const uint16_t duration)
{
    uint16_t i;
    
    i = (uint16_t) (TH0 << 8) + TL0;
    
    if (i >= duration)
        return PASS;
    else
        return FAIL;
}

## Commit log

2014-10-31 Updated BOM
    [LC-4102a bill of materials pcb.ods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]
2014-11-26 BOM update
    [LC-4102a bill of materials pcb.ods, LC-4102a bill of materials top.ods]
2014-12-09 Moved into own folder
    [LC-4102a bill of materials pcb.ods, LC-4102a bill of materials top.ods]
2014-12-09 Fixed outcommented watch dog timer disabling
    [microcontroller.c]
2014-12-09 Removed bug of watch dog timer
2015-01-06 fixed bug
    [assembly.igs, back panel.igs, case.igs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]
